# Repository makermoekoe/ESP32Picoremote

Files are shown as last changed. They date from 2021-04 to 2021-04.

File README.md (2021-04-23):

# ESP32PicoD4_TFT_Remote

</a>

WiFi remote based on ESP32 Pico D4 MCU and a beautiful 160x80 pixels mini TFT display. Additionally there is a I2C temperature & humidity sensor as well as an accelerometer on board.

Assembling video is on my [Youtube](https://youtu.be/5vRy--YCx7k).

The power latching circuit ensures that the ESP32 Pico D4 don't need to be in deep sleep mode while in OFF state. This puts it down to around 3µA during 'sleep', due to the battery protection. It can be woke up only by the middle button. The battery protection occupies reverse voltage protection through the mosfet. Overdischarge voltage of the XB5353A is 2.4volts, which is only for safety reasons. The battery voltage should always be checked with the voltage divider, which gives you an estimation of the battery state.

Main components are:
- ESP32 Pico D4
- CP2102N USB to serial bridge
- 160x80px ST7735 13pin TFT display
- HDC1080 temperature and humidity sensors
- LIS3DHTR accelerometer
- WS2812 LEDs
- XB5353A battery protection
- SE7401U polarity
- MCP73831 charging
- RT9193 regulator
- Molex 3D antenna

## Circuit & PCB

`pico32_remote_v1.0` was the initial schematic of this PCB. Unfortunately it occupies a few mistakes:
- Button two is connected to the ESP32 directly behind the button, which gives `VCC` directly to one of the GPIOs of the MCU - meh. The 1k resistor should be between the pulldown and the button.
- Furthermore the footprint of the LIS3DHTR is mirrored (not visible in the schematics).
- Last but not least the `VUSB` of the USB-C connector and the power selection circuit wasn't connected properly because the VUSB on one side was just a label and not the name of connection itself - shame on me.

All these mistakes are fixed in version 1.1. Additionally I have added a USB activation diode, which enables the latching circuit ones a USB cable is plugged into the board. This is nice to have if you want to visualize battery charging. Another advantage is that one of the buttons don't have to be pressed during firmware upload.

## Code

Check out the code in the 'code' section. It is used in PlatformIO, but can be shifted to Arduino IDE easily. The code is exactly the same.

The ST7735 display can be used easily with the [TFT_eSPI library](https://github.com/Bodmer/TFT_eSPI) by Bodmer. This library comes with a `User_Setup.h` to setup the dedicated display you are using. I have attached this file for this specific board in the code section of this repo.

Another nice library to play little GIFs on that tiny display is the [AnimatedGIF library](https://github.com/bitbank2/AnimatedGIF) by Larry Bank. He shared a nice tool for converting GIFs to a code array as well.

## Milled case

It is not yet optimized but the bottom part is looking great. The top part should move left and right while pushing the buttons, unfortunately it doesn't due to the small holes in PCB and bottom part. An easy solution would be to use two elongated holes in the top part (the screw heads would be visible on the top part).

When you have questions then feel free to ask.

Have fun! :)

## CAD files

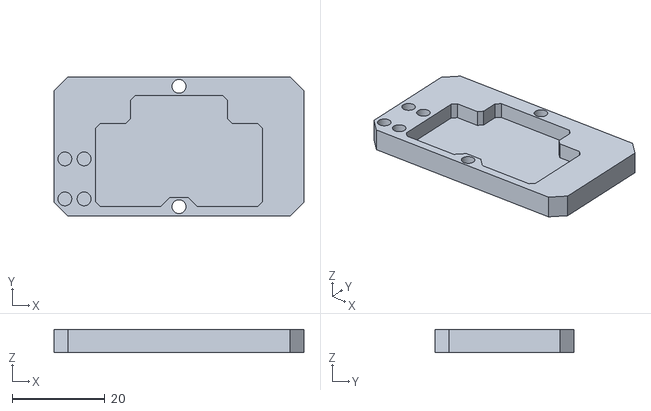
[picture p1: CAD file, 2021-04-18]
case/esp32picoremote_bot_v1_0.stl
54.0 x 30.0 x 5.00

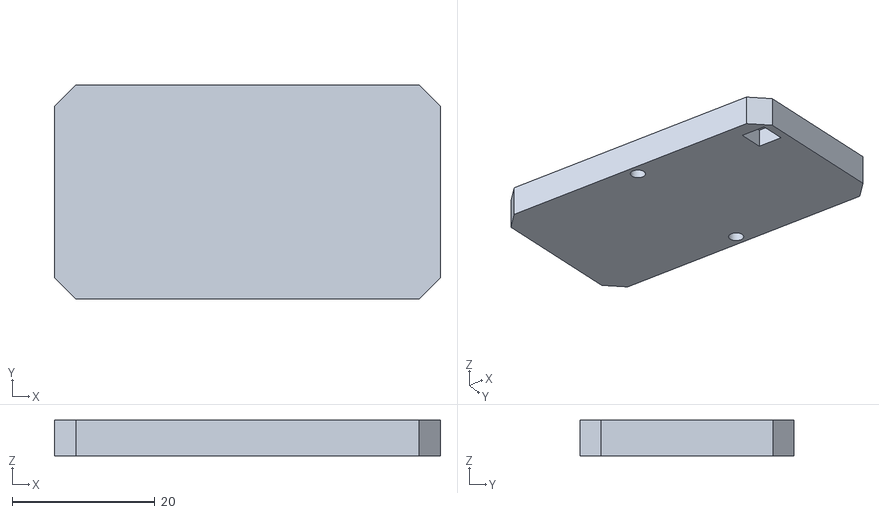
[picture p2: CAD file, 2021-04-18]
case/esp32picoremote_top_v1_0.stl
54.0 x 30.0 x 5.00

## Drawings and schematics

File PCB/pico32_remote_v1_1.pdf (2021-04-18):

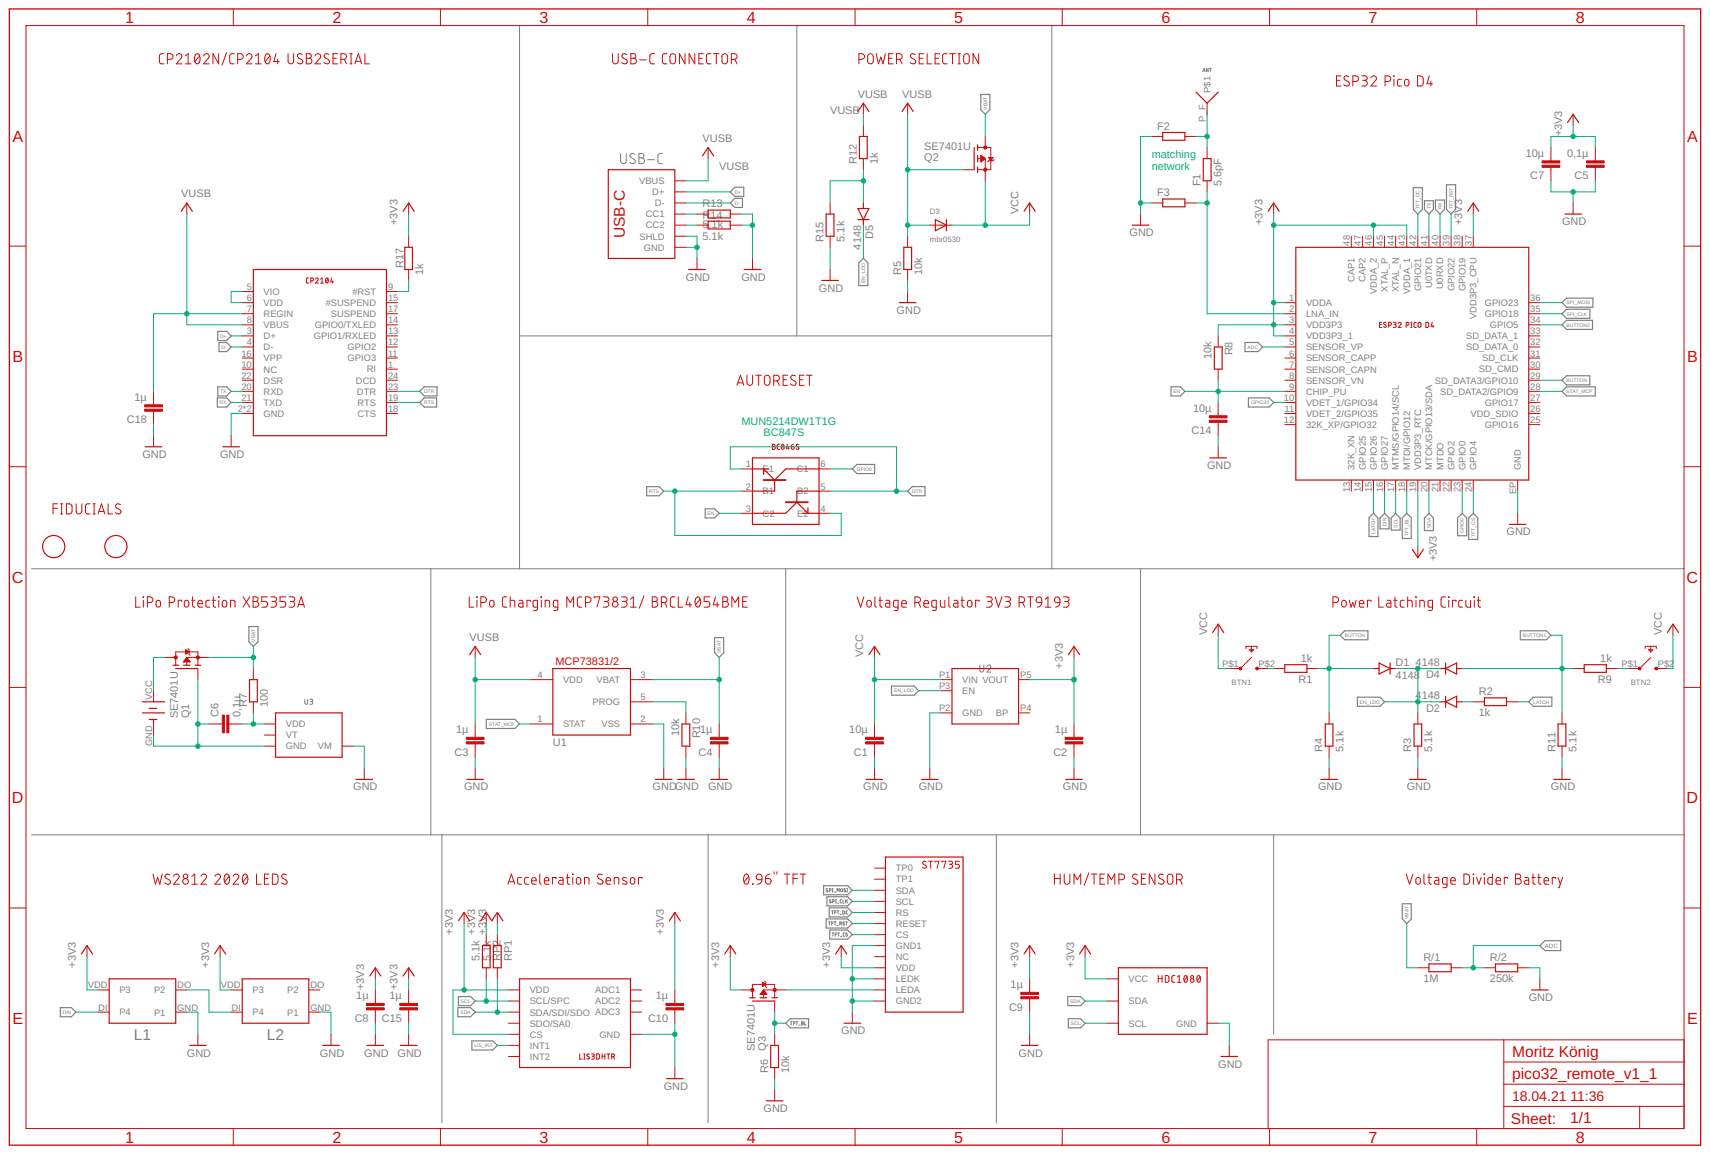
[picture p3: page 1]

VUSB | VUSB

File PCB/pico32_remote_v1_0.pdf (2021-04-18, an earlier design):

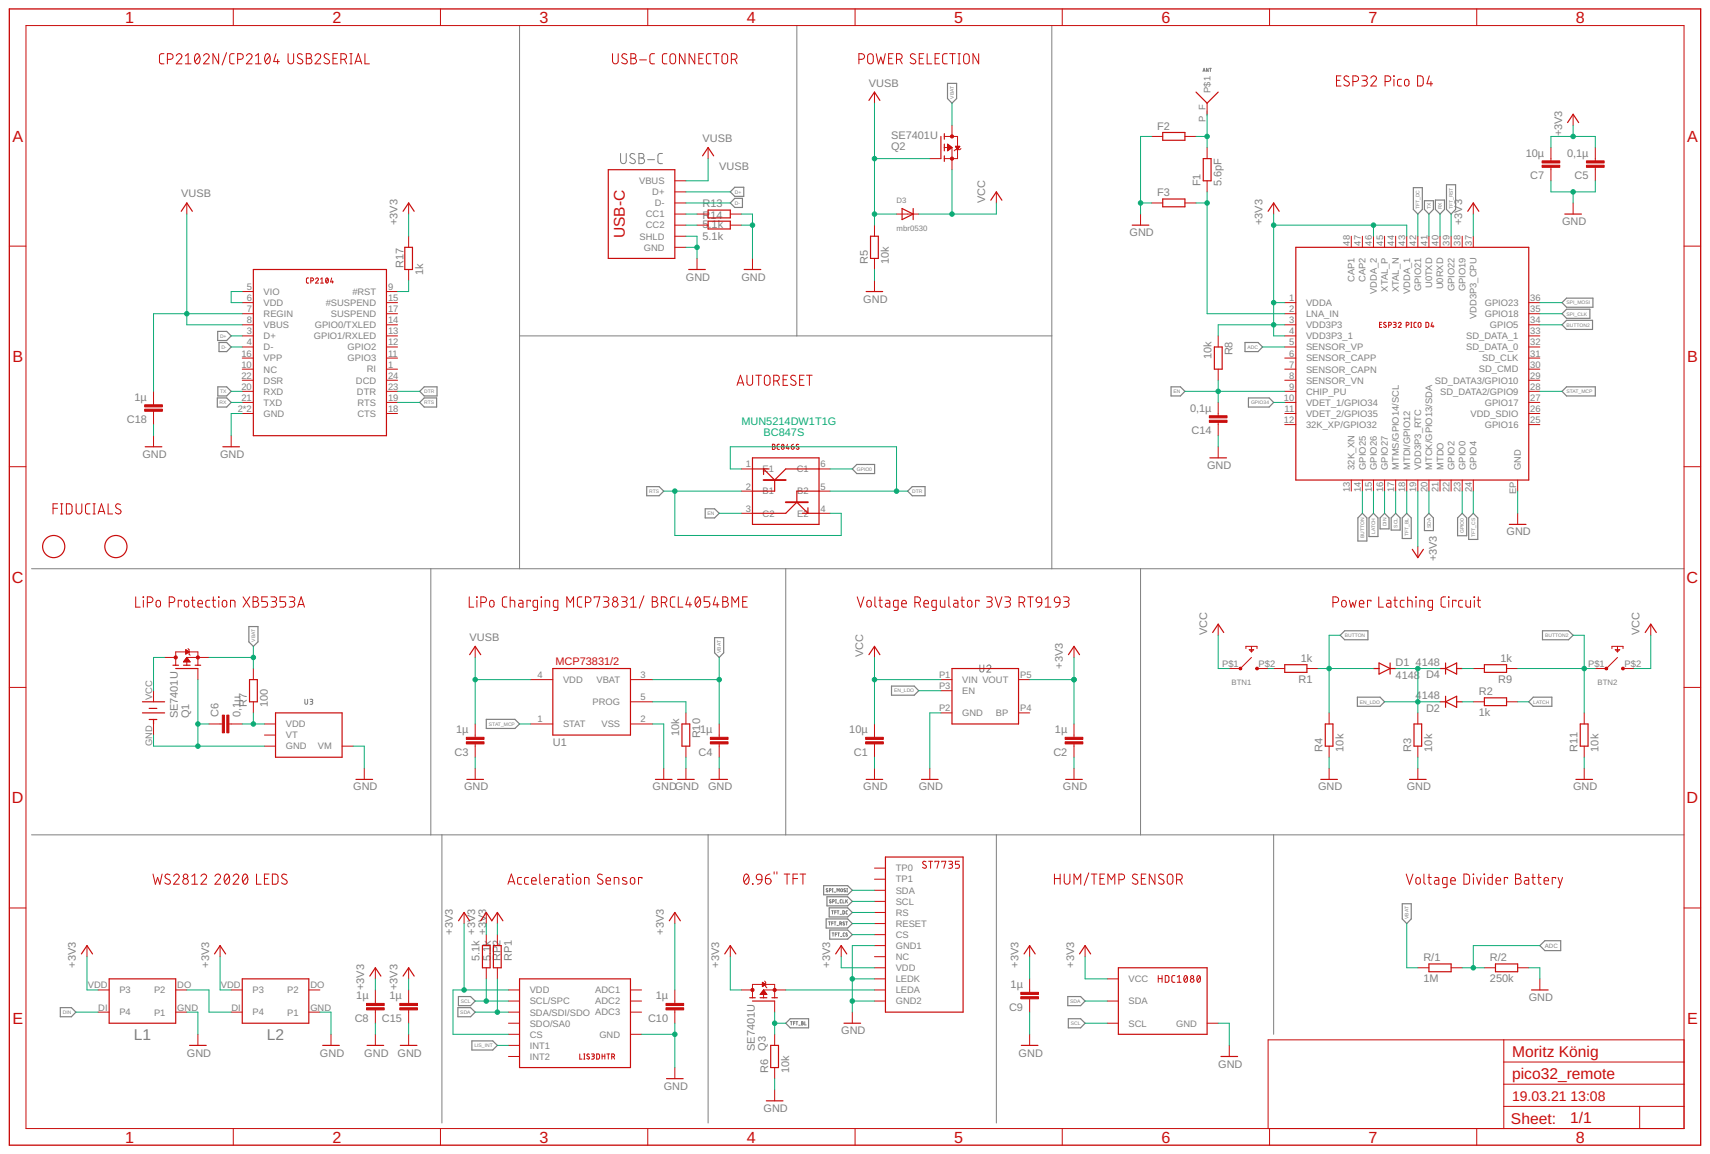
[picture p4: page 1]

VUSB | VUSB

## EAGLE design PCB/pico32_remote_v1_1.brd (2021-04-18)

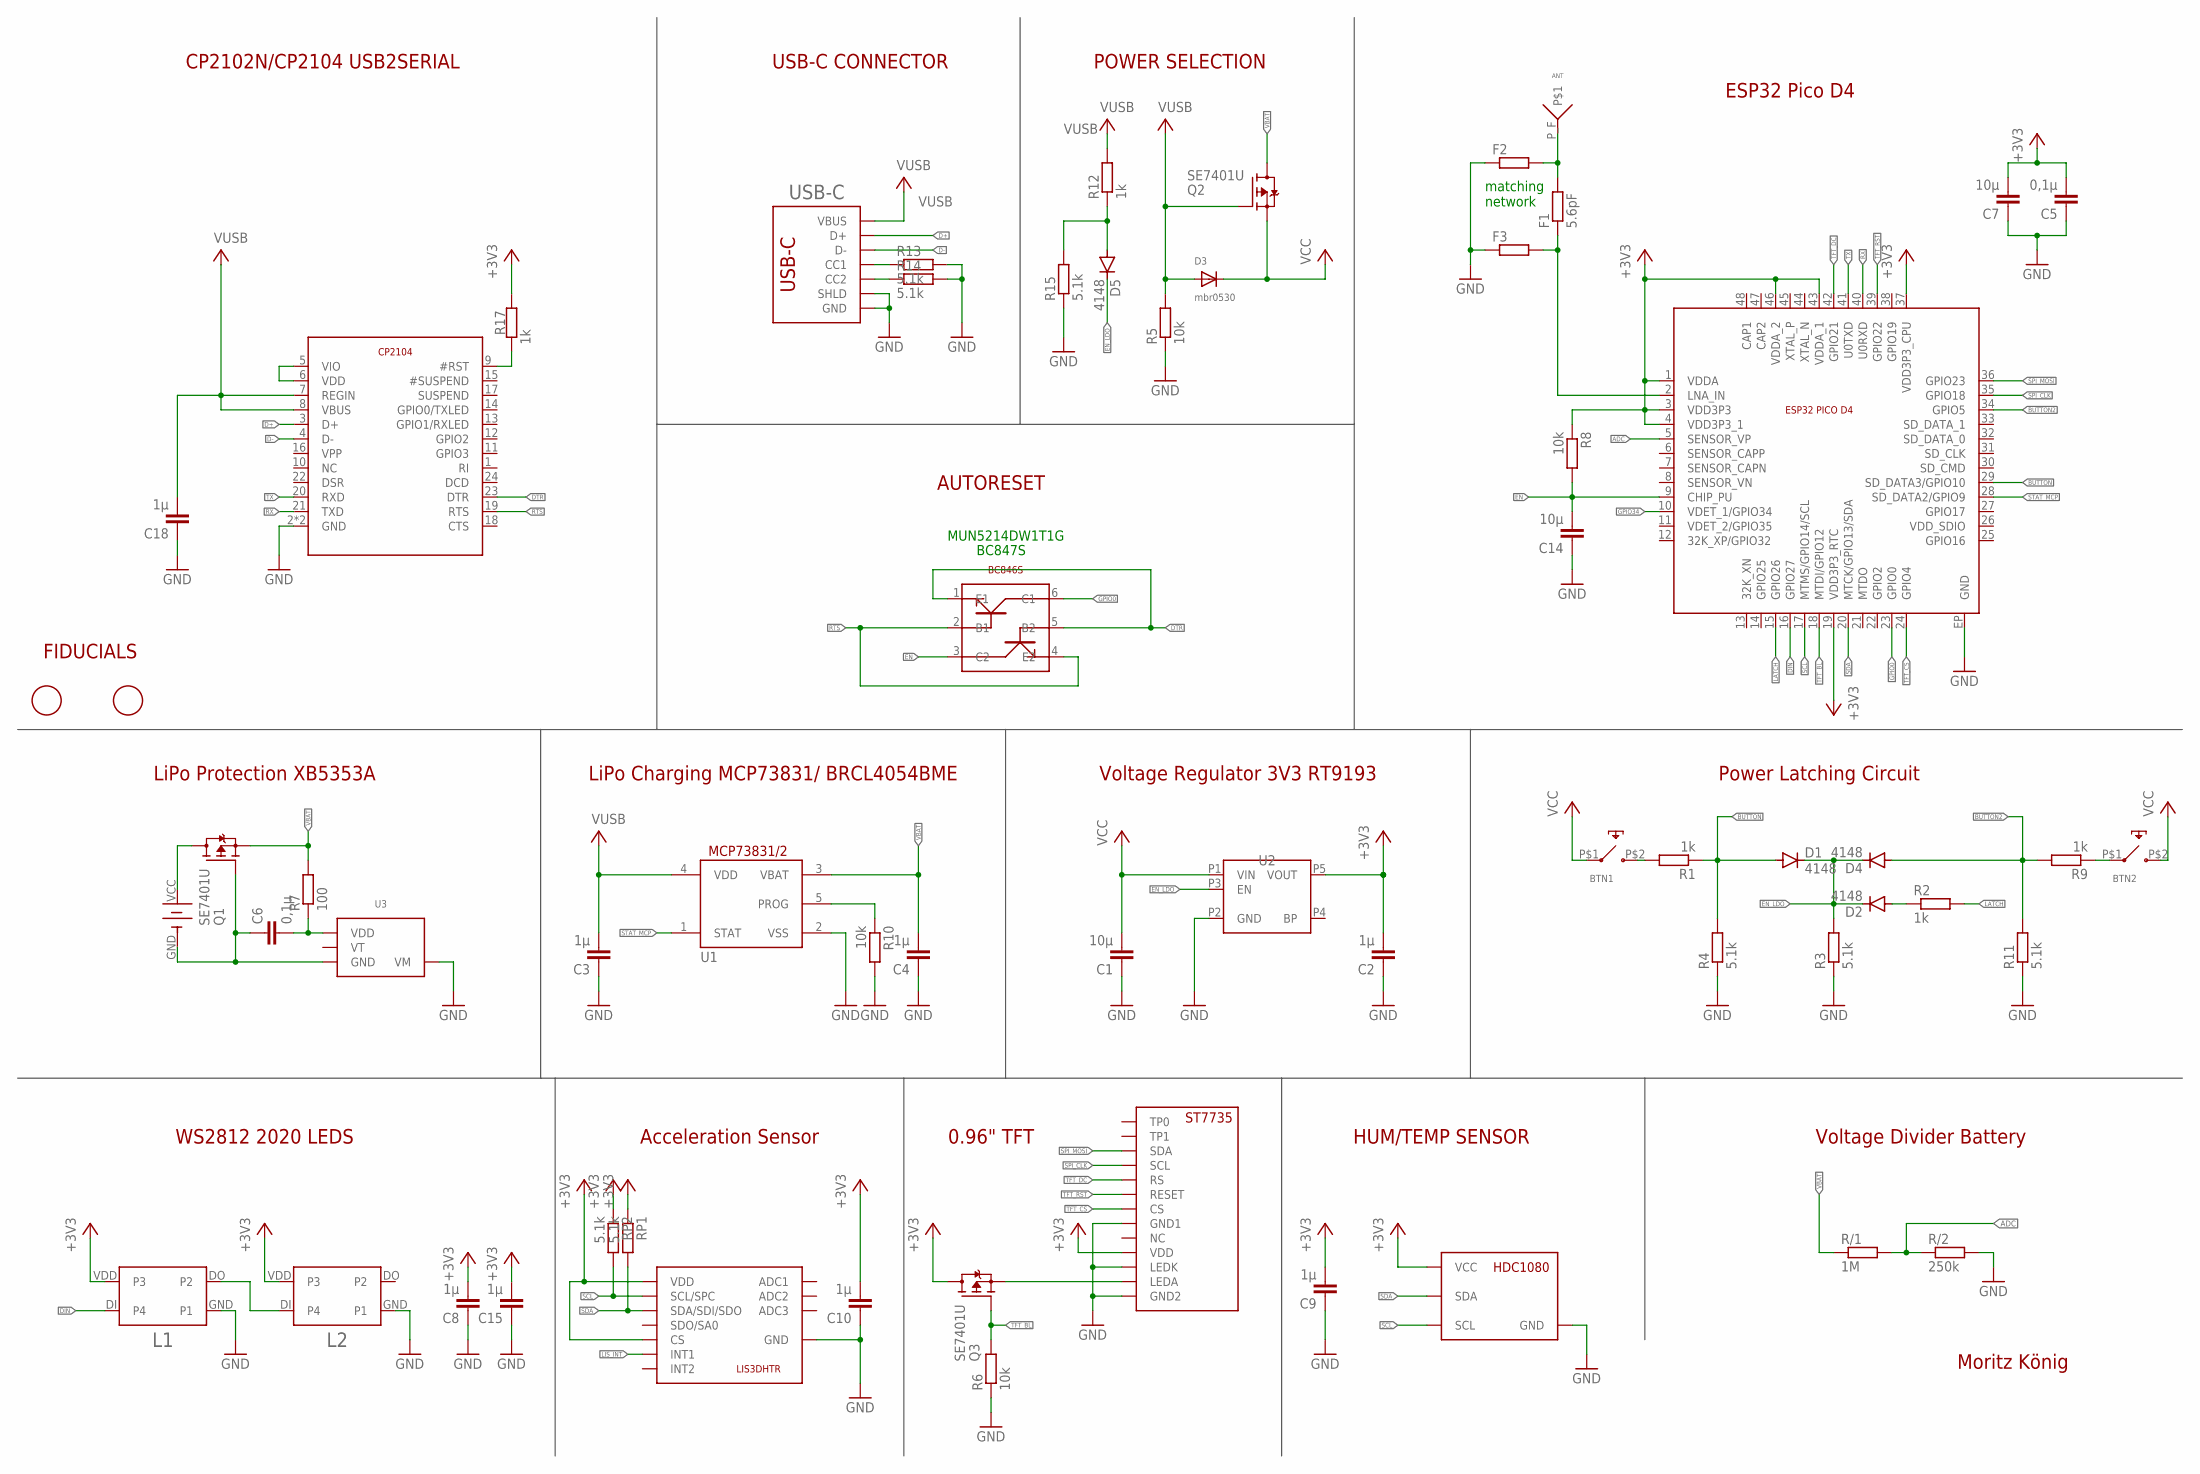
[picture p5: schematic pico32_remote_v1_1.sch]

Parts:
ANT: MOLEX_ANT_3D
BTN1, BTN2: BUTTON_6X6_SILICON; BUTTON_SILICON
C1, C7: 10µ; C0603
C2: 1µ; C0603
C3, C4, C8, C9, C10, C15, C18: 1µ; R0402
C5: 0,1µ; C0603
C6: 0,1µ; R0402
C14: 10µ; C0402K
D1, D2, D4, D5: 4148; SOD523
D3: mbr0530; SOD-123FL
ESP32: ESP32_PICO_D4_LP; QFN-48_LONG
F1: 5.6pF; R0402
F2, F3: R-EU-0402-WOKEEPOUT; R0402
L1, L2: WS2812_2020
Q1, Q2, Q3: SE7401U; SOT323
R1, R2, R9, R12, R17: 1k; R0402
R3, R4, R11, R13, R14, R15: 5.1k; R0402
R5, R6, R8, R10: 10k; R0402
R7: 100; R0402
R/1: 1M; R0402
R/2: 250k; R0402
RP1, RP2: 5.1k; R0402
U1: BRCL4054BME; SOT23-5L
U2: RT9193_SC70-5; SC-70-5
U3: XB5353A; SOT23-5
U4: LIS3DHTR; LGA_16_LIS3DHTR
U5: CP2102N; QFN24-4X4
U6: MUN5214DW1T1G; SOT363
U7: HDC1080; WSON08_HDC1080
U$2: 2450_BATTERYHOLDER_SMD
U$4: ST7735_096TFT_TWISTED
U$6, U$7: FIDUCIAL; FIDUCIAL_1MM
USB-C: USB_C_C393939; USBC_C393939

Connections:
+3V3: C2.2, C5.2, C7.2, C8.2, C9.2, C10.2, C15.2, ESP32.1 (VDDA), ESP32.3 (VDD3P3), ESP32.4 (VDD3P3_1), ESP32.19 (VDD3P3_RTC), ESP32.37 (VDD3P3_CPU), ESP32.43 (VDDA_1), ESP32.46 (VDDA_2), L1.VDD (P3), L2.VDD (P3), Q3.3 (D), R8.1, R17.2, RP1.1, RP2.1, U2.P5 (VOUT), U4.P$1 (VDD), U4.P$8 (CS), U4.P$14 (VDD), U7.P5 (VCC), U$4.P10 (VDD)
ADC: ESP32.5 (SENSOR_VP), R/1.2, R/2.1
ANTENNA1: ANT.P_F, F1.2, F2.2
BUTTON: D1.A, ESP32.29 (SD_DATA3/GPIO10), R1.1, R4.2
BUTTON2: D4.A, ESP32.34 (GPIO5), R9.2, R11.2
D+: U5.3 (D+), USB-C.A6 (D+), USB-C.B6 (D+)
D-: U5.4 (D-), USB-C.A7 (D-), USB-C.B7 (D-)
DIN: ESP32.16 (GPIO27), L1.DI (P4)
DTR: U5.23 (DTR), U6.1 (E1), U6.5 (B2)
EN: C14.2, ESP32.9 (CHIP_PU), R8.2, U6.3 (C2)
EN_LDO: D1.C, D2.C, D4.C, D5.C, R3.2, U2.P3 (EN)
GND: C1.1, C2.1, C3.1, C4.1, C5.1, C7.1, C8.1, C9.1, C10.1, C14.1, C15.1, C18.1, ESP32.EP (GND), F2.1, F3.1, L1.GND (P1), L2.GND (P1), R3.1, R4.1, R5.1, R6.1, R10.2, R11.1, R13.2, R14.2, R15.1, R/2.2, U1.2 (VSS), U2.P2 (GND), U3.4 (VM), U3.5 (VM), U4.P$5 (GND), U4.P$10 (GND), U4.P$12 (GND), U5.2 (GND), U5.EXP (GND), U7.P2 (GND), U$4.P8 (GND1), U$4.P11 (LEDK), U$4.P13 (GND2), USB-C.A1B12 (GND), USB-C.B1A12 (GND), USB-C.S1 (SHLD), USB-C.S2 (SHLD), USB-C.S3 (SHLD), USB-C.S4 (SHLD)
GPIO0: ESP32.23 (GPIO0), U6.6 (C1)
GPIO34: ESP32.10 (VDET_1/GPIO34)
LATCH: ESP32.15 (GPIO26), R2.2
LIS_INT: U4.P$11 (INT1)
unnamed: U5.5 (VIO), U5.6 (VDD)
unnamed: BTN2.P$1 (P1), R9.1
unnamed: Q3.2 (S), U$4.P12 (LEDA)
unnamed: ESP32.2 (LNA_IN), F1.1, F3.2
unnamed: C6.2, R7.1, U3.3 (VDD)
unnamed: D5.A, R12.1, R15.2
unnamed: C6.1, Q1.1 (G), U3.2 (GND), U$2.GND
unnamed: Q1.3 (D), U$2.VCC
unnamed: L1.DO (P2), L2.DI (P4)
unnamed: BTN1.P$2 (P2), R1.2
unnamed: D2.A, R2.1
unnamed: R14.1, USB-C.B5 (CC2)
unnamed: R10.1, U1.5 (PROG)
unnamed: R13.1, USB-C.A5 (CC1)
unnamed: R17.1, U5.9 (#RST)
RTS: U5.19 (RTS), U6.2 (B1), U6.4 (E2)
RX: ESP32.40 (U0RXD), U5.21 (TXD)
SCL: ESP32.17 (MTMS/GPIO14/SCL), RP2.2, U4.P$4 (SCL/SPC), U7.P6 (SCL)
SDA: ESP32.20 (MTCK/GPIO13/SDA), RP1.2, U4.P$6 (SDA/SDI/SDO), U7.P1 (SDA)
SPI_CLK: ESP32.35 (GPIO18), U$4.P4 (SCL)
SPI_MOSI: ESP32.36 (GPIO23), U$4.P3 (SDA)
STAT_MCP: ESP32.28 (SD_DATA2/GPIO9), U1.1 (STAT)
TFT_BL: ESP32.18 (MTDI/GPIO12), Q3.1 (G), R6.2
TFT_CS: ESP32.24 (GPIO4), U$4.P7 (CS)
TFT_DC: ESP32.42 (GPIO21), U$4.P5 (RS)
TFT_RST: ESP32.39 (GPIO22), U$4.P6 (RESET)
TX: ESP32.41 (U0TXD), U5.20 (RXD)
VBAT: C4.2, Q1.2 (S), Q2.3 (D), R7.2, R/1.1, U1.3 (VBAT)
VCC: BTN1.P$1 (P1), BTN2.P$2 (P2), C1.2, D3.C, Q2.2 (S), U2.P1 (VIN)
VUSB: C3.2, C18.2, D3.A, Q2.1 (G), R5.2, R12.2, U1.4 (VDD), U5.7 (REGIN), U5.8 (VBUS), USB-C.A4B9 (VBUS), USB-C.B4A9 (VBUS)

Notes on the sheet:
Moritz König
Voltage Divider Battery
LiPo Protection XB5353A
LiPo Charging MCP73831/ BRCL4054BME
Voltage Regulator 3V3 RT9193
Power Latching Circuit
WS2812 2020 LEDS
BC847S
USB-C CONNECTOR
CP2102N/CP2104 USB2SERIAL
AUTORESET
MUN5214DW1T1G
Acceleration Sensor
ESP32 Pico D4
POWER SELECTION
HUM/TEMP SENSOR
0.96" TFT
FIDUCIALS
matching network

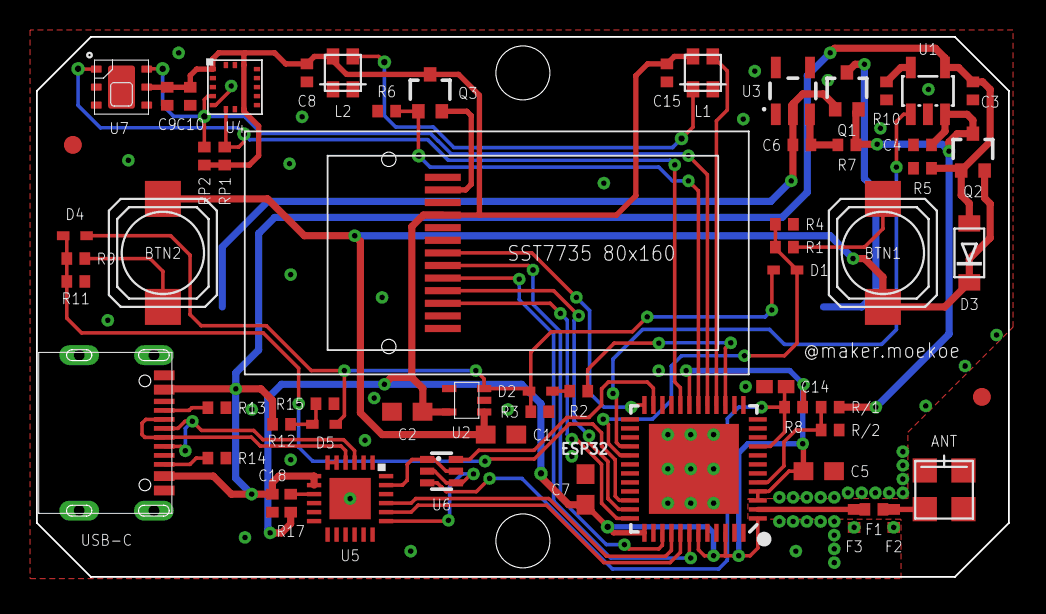
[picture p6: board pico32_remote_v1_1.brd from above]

Board: 2 copper layers, 54.0 x 30.0 mm, 62 parts (1 on the bottom side), 44 nets.

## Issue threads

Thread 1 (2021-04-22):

Latching Circuit

mekesim, 2021-04-22:
Hi Sir,
thanks for your sharing such excellent project.
I have a question about the latching circuit. How does it works, could you explain it please? I can find some basic work flow of it.

- while USB insert, EN_LDO high, it will enable the LDO.
- Button 1 or Button 2 pushed, EN_LDO high, it will enable the LDO.
- LATCH low, power off LDO, right?

Why there are tow button, how about just one button?

makermoekoe, 2021-04-23:
Hey, thank you!

Basically you have mentioned all the important features. It is as simple as controlling the enable pin of the LDO. If it's high, the LDO will deliver power to the MCU and all the devices which are connected to the output of the LDO. If not, it won't. As you have stated, the enable pin can be controlled via both buttons and a specific GPIO of the MCU.

Basic scenario is:
1. Press one of the two buttons (for other designs this could be even more buttons)
2. Hold the GPIO high (in fact the enable pin will be held high) so that the LDO will still deliver power once the button is released
3. If your program is done, you can just set the GPIO low and the MCU will shut down

For the newest version of the schematic and PCB I have added the enable control via USB voltage. Once it is connected to 5V it will pull the enable pin high. This won't affect the battery because once a USB voltage is connected the whole board (or in detail: the VCC line) is powered via the 5V USB voltage (through the diode D3). And, of course, the battery will be charged in this state.

Hope this clarifies it a bit more. If you still have questions feel free to ask!

mekesim, 2021-04-25:
Hi Sir,
thanks for your explain. I'm clear now.

An other question.
U3 is able to do reverse voltage protection,  why do you add Q1? Any other consideration?

makermoekoe, 2021-04-27:
Yes, you're probably right. I mixed up two circuits and haven't noticed that I've doubled the polarity protection...
Will fix it in the next revision!

Closed 2021-04-27.

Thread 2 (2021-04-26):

Auto RESET USB

custanator, 2021-04-26:
Hi!
Thanks for posting a good project!
On Instagram, you wrote about the problem of automatic firmware management via USB
In your circuit, there are no resistors in a pair of transistors.
They are present in the official scheme of NodeMСU.
Maybe this is the problem?

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

makermoekoe, 2021-04-27:
The BC847s is a dual npn transistor which will need two resistors for sure. The MUN5214DW1 has exactly the same pinout but it includes a simple bias resistor network. Therefore, the two resistors on the base are not necessary in this case. You can check the datasheet [here](https://www.onsemi.com/pdf/datasheet/dtc114yd-d.pdf).

The problem which I've mentioned on Instagram (which results in this huge pcb creature) was just a wrong capacitor value for the enable pin of the ESP32. It needs 10uF there.

custanator, 2021-04-27:
All clear. Thank you!

Closed 2021-04-27.

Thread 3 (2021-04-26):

What about PMIC?

custanator, 2021-04-26:
Have you thought about replacing all the power supply controls with a microcircuit PMIC (Power Management IC)?

Example: X-Powers AXP173
It already contains:
- Power Path (Power selection BAT/USB)
- 2 DC/DC
- 4 LDO
- Charge control
- Gas Gauge (how much charge is left in the battery)
- Button On/Off
- QFN-32

Using PMIС would greatly simplify the circuit :)

mekesim, 2021-04-27:
So powerful!

custanator, 2021-04-27:
Other variants

- AMS AS3701 –– Power Path, 1 DC/DC, 2 LDO, WLCSP-20, charger, GPIO and button
- Maxim MAX20353 –– Power Path, 3 DC/DC, 2 LDO, WLP-56, charger, gas gauge, GPIO, button
- Dialog DA9070 –– Power Path, 1 DC/DC, 3 LDO, WLCSP-42, charger, gas gauge (ADC), watchdog, button
- TI TPS6572x –– Power Path, 1 DC/DC, 1 LDO, WQFN-32, DSBGA-25, charger, GPIO, button
- Qorvo (Active Semi) ACT81460 –– Power Path, 4 DC/DC, 3 LDO, 1 HVB, WLCSP-49, charger, 4 GPIO, button
- Microchip MCP73871 — Power Path, QFN-20, charger.

makermoekoe, 2021-04-27:
Wow, thanks for this nice table of PMICs! I will check them all later the day.

But what about power consumption in shutdown state? At first sight it seems they're all using at least 25uA of power... Nevertheless, this would combine everything in just one chip and make the PCB more beautiful

custanator, 2021-04-27:
Yes, X-Powers AXP173 Off mode - 27uA. IMHO, its normal =)

makermoekoe, 2021-04-27:
Well, it is definitely low power! But the circuit in this project consumes just about 3uA which is related to the battery protection only.
I will have a deeper look on such a chip for upcoming projects 👌🏻

Closed 2021-04-27.

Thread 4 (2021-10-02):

Buttons

tamasharasztosi, 2021-10-02:
Hey!
Could you please tell me what do you mean by “ It can be woke up only by the middle button.”?

As the schematic shows it should be powered on by both of the buttons or if not then which one is the middle button?

Thank you!

Closed 2021-11-30.

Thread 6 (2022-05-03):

Two question (USB-C and Battery)

Theagainmen, 2022-05-03:
Hello all,

Thanks for creating such an awesome project! I really learn a lot from looking at the schematics and code.

For a project I am working on I wanted to use the USB-C part from your schematics. However I find many different variants of the USB-C, some with just 6 pins, up to 32 with many options in between. In your schematic you use one that only shows 7 pins, do you maybe have the exact component name of the USB-C you have used?

About the battery part I had also a question, you use the XB5353A (protection) and MCP73831 (charge) to manage the LiPo battery, I'm wondering if these IC's allow the battery to be discharged at the same time it's charged? The TP4056 for example does not allow this, since this can result in an overcharge failure detection, but I'm unable to find anything about it in the IC datasheets you have used.

Thanks for any help :)

PathToLife, 2022-05-03:
Regarding the second part of this issue
- https://electronics.stackexchange.com/questions/539946/recharging-a-lipo-battery-while-using-it

Charger ICs that can support a load while still charging correctly exist, but your MCP73831 isn't one of them. The [MCP73871](https://ww1.microchip.com/downloads/en/DeviceDoc/MCP73871-Data-Sheet-20002090E.pdf) is; it supports load sharing and can supply a load while charging the battery.

Theagainmen, 2022-05-04:
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

Thanks! I'll look more into this. Do you maybe know how to even find IC's like this? Like what search engine/site do you go to and what to type in? Also to get some IC's that are actually used by more people and affordable :)

Theagainmen, 2022-05-04:
> About USB C... Yes, they might have 32 pins, but they are doubled. As the C standard has two rows, with the same function of pins, top and bottom pins should be connected. Say DN1 and DN2 are basically the same but on opposite sides.
>
> In basic usage, you need DP, DN, CC, and Power pins. Do not be confused about CC1 and CC2, DN1 and DN2, and similar. You just have to connect those 1 and 2's. CC pins are a source to sink pins. Just check some datasheets.

Thanks, I've been checking some datasheets but I'm still not 100% whether they are compatible.

If I just connect these pins in my KiCad project: `VUSB, CC1, CC2, D1-, D1+, SHIELD, GND` on this [USB-C (click)](https://datasheet.lcsc.com/lcsc/2103051833_Jing-Extension-of-the-Electronic-Co--918-418K2023S40001_C167321.pdf ), and leave the rest unconnected, will that work?

ITstreet1, 2022-05-04:
You only need VUSB, GND, D- and D+ if you are using it with a standard USB (PC or regular charger). Let's say for uploading a software. If you are using it with a charger that uses CC lines you must connect them, too. I would connect both CCs with a 5.1K to a GND just in case. The rest pins you can leave unconnected.

You can check the schematic here for the Picoremote.

As for the MCP73831, it is so easy to type in Google.

https://eu.mouser.com/new/microchip/microchip-mcp73831-2-controllers/
https://www.digikey.com/en/products/detail/microchip-technology/MCP73831T-2ACI-OT/964301

...

Theagainmen, 2022-05-04:
Ok thank you @ITstreet1. I found this [USB-C](https://datasheet.lcsc.com/lcsc/2103051833_Jing-Extension-of-the-Electronic-Co--918-418K2023S40001_C167321.pdf ) and I'm connecting it like this:
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
I'm pretty sure this works, but if you see anything odd, please let me know!

> As for the MCP73831, it is so easy to type in Google.

As for this I was more talking about finding IC's **like this**. Like what tool or engine can I use to find IC's that charge LiPo and have X and Y specs. I know stuff like Mouser, but when I type in LiPo charger I get so many options, and many of them are not what I'm looking for.

ITstreet1, 2022-05-05:
Schematic look ok to me.

> As for this I was more talking about finding IC's like this. Like what tool or engine can I use to find IC's that charge LiPo and have X and Y specs. I know stuff like Mouser, but when I type in LiPo charger I get so many options, and many of them are not what I'm looking for.

I don't know if such an online tool exists.

Closed 2022-09-07.

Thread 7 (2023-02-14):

Battery protection circuit

MukeshKumarRattu, 2023-02-14:
Hello sir , i saw your work its awesome. I am little confused about the battery protection circuit. Its a P channel mosfet you used there and gate connected with the Gnd. Can you please explain me how it works because protection ic have its own VM which also connected to Gnd. I really want to know how this circuit work's

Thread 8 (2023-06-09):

Porting compilation problem

Camellia-ks, 2023-06-09:
Hello, I encountered "No hardware SPI pins defined. All SPI access will default to bitbanged output" when I was porting to arduino. Is there any impact on this?

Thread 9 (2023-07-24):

Does the latching circuit send higher voltage to MCU?

sam0910, 2023-07-24:
Greetings!
This is so neat product :)

Does the latching circuit send higher voltage to MCU?
BUTTON and BUTTON2 are only connected with 1K, 5.1K resistor,
so VCC(4.2V) divides to 3.51V, is it okay for the 3.3V MCU GPIO?

Thank you so much

Closed 2024-01-29.

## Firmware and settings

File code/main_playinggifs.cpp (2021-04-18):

#include <Arduino.h>
#include <driver/dac.h>
#include <FastLED.h>
#include <Wire.h>
#include "ClosedCube_HDC1080.h"

#include <AnimatedGIF.h>
#include <TFT_eSPI.h>
#include <SPI.h>
#include "../test_images/moekoe2.h"
//#include "../test_images/badgers.h"
//#include "../test_images/homer.h"
//#include "../test_images/homer_tiny.h"
//#include "../test_images/pattern.h"
//#include <Adafruit_LIS3DH.h>
//#include <Adafruit_Sensor.h>

ClosedCube_HDC1080 hdc;
TFT_eSPI tft = TFT_eSPI();
//Adafruit_LIS3DH lis = Adafruit_LIS3DH();


#define DISPLAY_WIDTH 160
#define DISPLAY_HEIGHT 80
AnimatedGIF gif;

#define NORMAL_SPEED
#define GIF_IMAGE1 moekoe2

struct box {
  uint8_t left,top,width,height;
  uint32_t color,color_in;
  uint8_t border,radius;

  int left_in(){return left + border;}
  int top_in(){return top + border;}
  int width_in(){return width - 2*border;}
  int height_in(){return height - 2*border;}
};

box bbox_left = {1,2,2,76,TFT_WHITE,TFT_BLUE,0,2};
box bbox_right = {157,2,2,76,TFT_WHITE,TFT_BLUE,0,2};

box center = {bbox_left.left+bbox_left.width,0,bbox_right.left-(bbox_left.left+bbox_left.width),80,0,0,0,0};

const int btn1 = 25;
const int btn2 = 5;
const int latch = 26;
const int led_pin = 27;
const int tft_bl = 12;
const int stat_mcp = 9;

#define NUM_LEDS 2
CRGB leds[NUM_LEDS];

bool ostate_left, state_left = false;
bool ostate_right, state_right = false;

void draw_buttons(bool left_pressed, bool right_pressed){
  tft.fillRect(bbox_left.left, bbox_left.top, bbox_left.width, bbox_left.height, TFT_BLACK);
  tft.fillRect(bbox_right.left, bbox_right.top, bbox_right.width, bbox_right.height, TFT_BLACK);

  tft.fillRoundRect(bbox_left.left, bbox_left.top, bbox_left.width, bbox_left.height, bbox_left.radius, bbox_left.color);
  tft.fillRoundRect(bbox_right.left, bbox_right.top, bbox_right.width, bbox_right.height, bbox_right.radius, bbox_right.color);

  if(left_pressed){
    tft.fillRoundRect(bbox_left.left_in(), bbox_left.top_in(), bbox_left.width_in(), bbox_left.height_in(), bbox_left.radius, bbox_left.color_in);
  }
  if(right_pressed){
    tft.fillRoundRect(bbox_right.left_in(), bbox_right.top_in(), bbox_right.width_in(), bbox_right.height_in(), bbox_right.radius, bbox_right.color_in);
  }
}

int read_buttons(bool &b1, bool &b2, bool upd_tft, bool upd_leds){
  b1 = digitalRead(btn2);
  b2 = digitalRead(btn1);
  if(upd_tft && (ostate_left != state_left || ostate_right != state_right)){
    draw_buttons(state_left, state_right);
    ostate_left = state_left;
    ostate_right = state_right;
  }
  if(upd_leds){
    leds[1] = CRGB(0,b1*150,0);
    leds[0] = CRGB(0,0,b2*150);
    FastLED.show();
  }
}

void update_hdc(){
  float temp_hdc = hdc.readTemperature();
  float hum_hdc = hdc.readHumidity();
  tft.fillRect(center.left, center.top, center.width, center.height, TFT_BLACK);
  tft.setTextColor(TFT_BLUE, TFT_BLACK);

  tft.setTextDatum(MC_DATUM);
  tft.drawString((String(temp_hdc) + "C"),50,40,2);
  tft.setTextDatum(MC_DATUM);
  tft.drawString((String(hum_hdc) + "%"),110,40,2);
}


#define BUFFER_SIZE 256
uint16_t usTemp[1][BUFFER_SIZE];
bool     dmaBuf = 0;
  
void GIFDraw(GIFDRAW *pDraw)
{
  uint8_t *s;
  uint16_t *d, *usPalette;
  int x, y, iWidth, iCount;

  // Displ;ay bounds chech and cropping
  iWidth = pDraw->iWidth;
  if (iWidth + pDraw->iX > DISPLAY_WIDTH)
    iWidth = DISPLAY_WIDTH - pDraw->iX;
  usPalette = pDraw->pPalette;
  y = pDraw->iY + pDraw->y; // current line
  if (y >= DISPLAY_HEIGHT || pDraw->iX >= DISPLAY_WIDTH || iWidth < 1)
    return;

  // Old image disposal
  s = pDraw->pPixels;
  if (pDraw->ucDisposalMethod == 2) // restore to background color
  {
    for (x = 0; x < iWidth; x++)
    {
      if (s[x] == pDraw->ucTransparent)
        s[x] = pDraw->ucBackground;
    }
    pDraw->ucHasTransparency = 0;
  }

  // Apply the new pixels to the main image
  if (pDraw->ucHasTransparency) // if transparency used
  {
    uint8_t *pEnd, c, ucTransparent = pDraw->ucTransparent;
    pEnd = s + iWidth;
    x = 0;
    iCount = 0; // count non-transparent pixels
    while (x < iWidth)
    {
      c = ucTransparent - 1;
      d = &usTemp[0][0];
      while (c != ucTransparent && s < pEnd && iCount < BUFFER_SIZE )
      {
        c = *s++;
        if (c == ucTransparent) // done, stop
        {
          s--; // back up to treat it like transparent
        }
        else // opaque
        {
          *d++ = usPalette[c];
          iCount++;
        }
      } // while looking for opaque pixels
      if (iCount) // any opaque pixels?
      {
        // DMA would degrtade performance here due to short line segments
        tft.setAddrWindow(pDraw->iX + x, y, iCount, 1);
        tft.pushPixels(usTemp, iCount);
        x += iCount;
        iCount = 0;
      }
      // no, look for a run of transparent pixels
      c = ucTransparent;
      while (c == ucTransparent && s < pEnd)
      {
        c = *s++;
        if (c == ucTransparent)
          x++;
        else
          s--;
      }
    }
  }
  else
  {
    s = pDraw->pPixels;

    // Unroll the first pass to boost DMA performance
    // Translate the 8-bit pixels through the RGB565 palette (already byte reversed)
    if (iWidth <= BUFFER_SIZE)
      for (iCount = 0; iCount < iWidth; iCount++) usTemp[dmaBuf][iCount] = usPalette[*s++];
    else
      for (iCount = 0; iCount < BUFFER_SIZE; iCount++) usTemp[dmaBuf][iCount] = usPalette[*s++];

#ifdef USE_DMA // 71.6 fps (ST7796 84.5 fps)
    tft.dmaWait();
    tft.setAddrWindow(pDraw->iX, y, iWidth, 1);
    tft.pushPixelsDMA(&usTemp[dmaBuf][0], iCount);
    dmaBuf = !dmaBuf;
#else // 57.0 fps
    tft.setAddrWindow(pDraw->iX, y, iWidth, 1);
    tft.pushPixels(&usTemp[0][0], iCount);
#endif

    iWidth -= iCount;
    // Loop if pixel buffer smaller than width
    while (iWidth > 0)
    {
      // Translate the 8-bit pixels through the RGB565 palette (already byte reversed)
      if (iWidth <= BUFFER_SIZE)
        for (iCount = 0; iCount < iWidth; iCount++) usTemp[dmaBuf][iCount] = usPalette[*s++];
      else
        for (iCount = 0; iCount < BUFFER_SIZE; iCount++) usTemp[dmaBuf][iCount] = usPalette[*s++];

#ifdef USE_DMA
      tft.dmaWait();
      tft.pushPixelsDMA(&usTemp[dmaBuf][0], iCount);
      dmaBuf = !dmaBuf;
#else
      tft.pushPixels(&usTemp[0][0], iCount);
#endif
      iWidth -= iCount;
    }
  }
} /* GIFDraw() */

void play_gif1(){
  if (gif.open((uint8_t *)GIF_IMAGE1, sizeof(GIF_IMAGE1), GIFDraw)) {
    Serial.printf("Successfully opened GIF; Canvas size = %d x %d\n", gif.getCanvasWidth(), gif.getCanvasHeight());
    tft.startWrite(); // The TFT chip slect is locked low
    while (gif.playFrame(true, NULL)) {
      yield();
    }
    gif.close();
    tft.endWrite(); // Release TFT chip select for other SPI devices
  }
}


void setup() {
  pinMode(latch,OUTPUT);
  digitalWrite(latch,HIGH);

  dac_output_disable(DAC_CHANNEL_1);

  pinMode(btn1,INPUT);
  pinMode(btn2,INPUT);
  Serial.begin(115200);
  Serial.println("start");

  pinMode(tft_bl,OUTPUT);
  digitalWrite(tft_bl,HIGH);

  Wire.begin(13,14);

  FastLED.addLeds<WS2812, led_pin, GRB>(leds, NUM_LEDS);
  FastLED.setBrightness(200);
  delay(1);
  for (int i = 0; i < NUM_LEDS; i++) leds[i] = CRGB(150, 0, 0);
  FastLED.show();

  hdc.begin(0x40);

  tft.init();
  tft.fillScreen(TFT_BLACK);
  tft.setRotation(3);

  gif.begin(BIG_ENDIAN_PIXELS);

  digitalWrite(tft_bl,LOW);

  play_gif1();

  //draw_buttons(0,0);
}



unsigned long t = millis();
unsigned long t_both_btn_pressed = 0;



void loop() {
  play_gif1();

  read_buttons(state_left, state_right, true, true);
  if(state_left && state_right){
    if(millis() > t_both_btn_pressed + 1000){
      //shut down device
      for (int i = 0; i < NUM_LEDS; i++) leds[i] = CRGB(150, 0, 0);
      FastLED.show();
      digitalWrite(latch,LOW);
      delay(200);
      while(digitalRead(btn1)) delay(100);
    }
  }
  else if(state_left){
    
  }
  else if(state_right){

  }
  else{
    t_both_btn_pressed = millis();
  }

  delay(10);

  /*if(millis() > t + 1000){
    update_hdc();
    t = millis();
  }*/
  
}

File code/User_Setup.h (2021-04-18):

//                            USER DEFINED SETTINGS
//   Set driver type, fonts to be loaded, pins used and SPI control method etc
//
//   See the User_Setup_Select.h file if you wish to be able to define multiple
//   setups and then easily select which setup file is used by the compiler.
//
//   If this file is edited correctly then all the library example sketches should
//   run without the need to make any more changes for a particular hardware setup!
//   Note that some sketches are designed for a particular TFT pixel width/height


// ##################################################################################
//
// Section 1. Call up the right driver file and any options for it
//
// ##################################################################################

// Define RP2040 to invoke optimised processor support (only for RP2040)
//#define RP2040

// Define STM32 to invoke optimised processor support (only for STM32)
//#define STM32

// Defining the STM32 board allows the library to optimise the performance
// for UNO compatible "MCUfriend" style shields
//#define NUCLEO_64_TFT
//#define NUCLEO_144_TFT

// STM32 8 bit parallel only:
// If STN32 Port A or B pins 0-7 are used for 8 bit parallel data bus bits 0-7
// then this will improve rendering performance by a factor of ~8x
//#define STM_PORTA_DATA_BUS
//#define STM_PORTB_DATA_BUS

// Tell the library to use 8 bit parallel mode (otherwise SPI is assumed)
//#define TFT_PARALLEL_8_BIT

// Display type -  only define if RPi display
//#define RPI_DISPLAY_TYPE // 20MHz maximum SPI

// Only define one driver, the other ones must be commented out
//#define ILI9341_DRIVER
#define ST7735_DRIVER      // Define additional parameters below for this display
//#define ILI9163_DRIVER     // Define additional parameters below for this display
//#define S6D02A1_DRIVER
//#define RPI_ILI9486_DRIVER // 20MHz maximum SPI
//#define HX8357D_DRIVER
//#define ILI9481_DRIVER
//#define ILI9486_DRIVER
//#define ILI9488_DRIVER     // WARNING: Do not connect ILI9488 display SDO to MISO if other devices share the SPI bus (TFT SDO does NOT tristate when CS is high)
//#define ST7789_DRIVER      // Full configuration option, define additional parameters below for this display
//#define ST7789_2_DRIVER    // Minimal configuration option, define additional parameters below for this display
//#define R61581_DRIVER
//#define RM68140_DRIVER
//#define ST7796_DRIVER
//#define SSD1963_480_DRIVER
//#define SSD1963_800_DRIVER
//#define SSD1963_800ALT_DRIVER
//#define ILI9225_DRIVER
//#define GC9A01_DRIVER

// Some displays support SPI reads via the MISO pin, other displays have a single
// bi-directional SDA pin and the library will try to read this via the MOSI line.
// To use the SDA line for reading data from the TFT uncomment the following line:

// #define TFT_SDA_READ      // This option is for ESP32 ONLY, tested with ST7789 and GC9A01 display only

// For ST7735, ST7789 and ILI9341 ONLY, define the colour order IF the blue and red are swapped on your display
// Try ONE option at a time to find the correct colour order for your display

//#define TFT_RGB_ORDER TFT_RGB  // Colour order Red-Green-Blue
#define TFT_RGB_ORDER TFT_BGR  // Colour order Blue-Green-Red

// For M5Stack ESP32 module with integrated ILI9341 display ONLY, remove // in line below

// #define M5STACK

// For ST7789, ST7735, ILI9163 and GC9A01 ONLY, define the pixel width and height in portrait orientation
#define TFT_WIDTH  80
// #define TFT_WIDTH  128
// #define TFT_WIDTH  240 // ST7789 240 x 240 and 240 x 320
// #define TFT_HEIGHT 160
// #define TFT_HEIGHT 128
// #define TFT_HEIGHT 240 // ST7789 240 x 240
// #define TFT_HEIGHT 320 // ST7789 240 x 320
#define TFT_HEIGHT 160 // GC9A01 240 x 240

// For ST7735 ONLY, define the type of display, originally this was based on the
// colour of the tab on the screen protector film but this is not always true, so try
// out the different options below if the screen does not display graphics correctly,
// e.g. colours wrong, mirror images, or stray pixels at the edges.
// Comment out ALL BUT ONE of these options for a ST7735 display driver, save this
// this User_Setup file, then rebuild and upload the sketch to the board again:

//#define ST7735_INITB
//#define ST7735_GREENTAB
//#define ST7735_GREENTAB2
// #define ST7735_GREENTAB3
// #define ST7735_GREENTAB128    // For 128 x 128 display
#define ST7735_GREENTAB160x80 // For 160 x 80 display (BGR, inverted, 26 offset)
//#define ST7735_REDTAB
//#define ST7735_BLACKTAB
//define ST7735_REDTAB160x80   // For 160 x 80 display with 24 pixel offset

// If colours are inverted (white shows as black) then uncomment one of the next
// 2 lines try both options, one of the options should correct the inversion.

//#define TFT_INVERSION_ON
//#define TFT_INVERSION_OFF


// ##################################################################################
//
// Section 2. Define the pins that are used to interface with the display here
//
// ##################################################################################

// If a backlight control signal is available then define the TFT_BL pin in Section 2
// below. The backlight will be turned ON when tft.begin() is called, but the library
// needs to know if the LEDs are ON with the pin HIGH or LOW. If the LEDs are to be
// driven with a PWM signal or turned OFF/ON then this must be handled by the user
// sketch. e.g. with digitalWrite(TFT_BL, LOW);

//#define TFT_BL   12            // LED back-light control pin
#define TFT_BACKLIGHT_ON LOW  // Level to turn ON back-light (HIGH or LOW)



// We must use hardware SPI, a minimum of 3 GPIO pins is needed.
// Typical setup for ESP8266 NodeMCU ESP-12 is :
//
// Display SDO/MISO  to NodeMCU pin D6 (or leave disconnected if not reading TFT)
// Display LED       to NodeMCU pin VIN (or 5V, see below)
// Display SCK       to NodeMCU pin D5
// Display SDI/MOSI  to NodeMCU pin D7
// Display DC (RS/AO)to NodeMCU pin D3
// Display RESET     to NodeMCU pin D4 (or RST, see below)
// Display CS        to NodeMCU pin D8 (or GND, see below)
// Display GND       to NodeMCU pin GND (0V)
// Display VCC       to NodeMCU 5V or 3.3V
//
// The TFT RESET pin can be connected to the NodeMCU RST pin or 3.3V to free up a control pin
//
// The DC (Data Command) pin may be labelled AO or RS (Register Select)
//
// With some displays such as the ILI9341 the TFT CS pin can be connected to GND if no more
// SPI devices (e.g. an SD Card) are connected, in this case comment out the #define TFT_CS
// line below so it is NOT defined. Other displays such at the ST7735 require the TFT CS pin
// to be toggled during setup, so in these cases the TFT_CS line must be defined and connected.
//
// The NodeMCU D0 pin can be used for RST
//
//
// Note: only some versions of the NodeMCU provide the USB 5V on the VIN pin
// If 5V is not available at a pin you can use 3.3V but backlight brightness
// will be lower.
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
